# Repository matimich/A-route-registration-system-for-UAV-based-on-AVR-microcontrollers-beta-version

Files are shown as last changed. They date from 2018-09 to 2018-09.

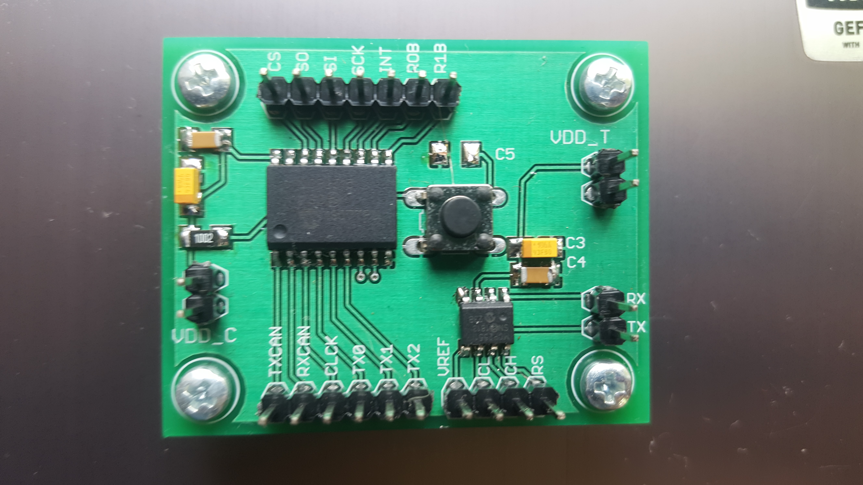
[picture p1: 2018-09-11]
EAGLE/CAN_module.jpg

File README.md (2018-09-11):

Author: Mateusz Michalski

Description:
A route registration system for UAV, based on AVR microcontrollers is a platform consisting of three ATmega microcontrollers, GPS module and an MicroSD card drive. One of the aims of the project was to learn as much communication interfaces as possible, that is why the project includes UART, I2C, SPI, CAN interfaces. All code has been written in C language. To communicate with MicroSD card drive "FatFs" library has been used. In addition, to make communication with CAN, MCP2515 module and MCP2551 transciver have been used. Working with this components reqiured to attached elements from "" library into the project.
Because project was made mostly for a educational purposes, additionaly, two PCB projects were designed and produced. One of them was a shrinked ATmega 32 starter kit and the second was the board to make communication with CAN between uC(board includes MCP2515 module and MCP2551 transciver).

The project was made as diploma thesis.

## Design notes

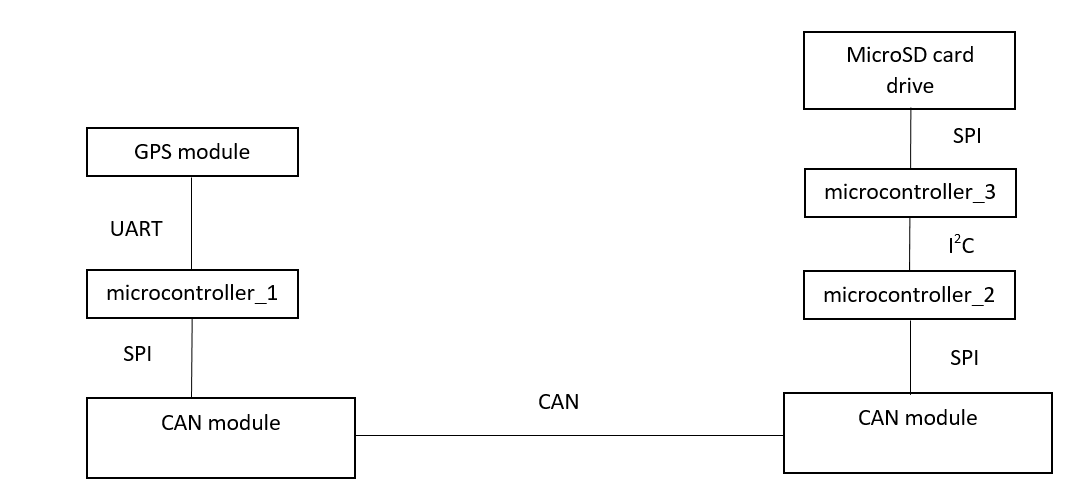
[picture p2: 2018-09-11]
scheme.png

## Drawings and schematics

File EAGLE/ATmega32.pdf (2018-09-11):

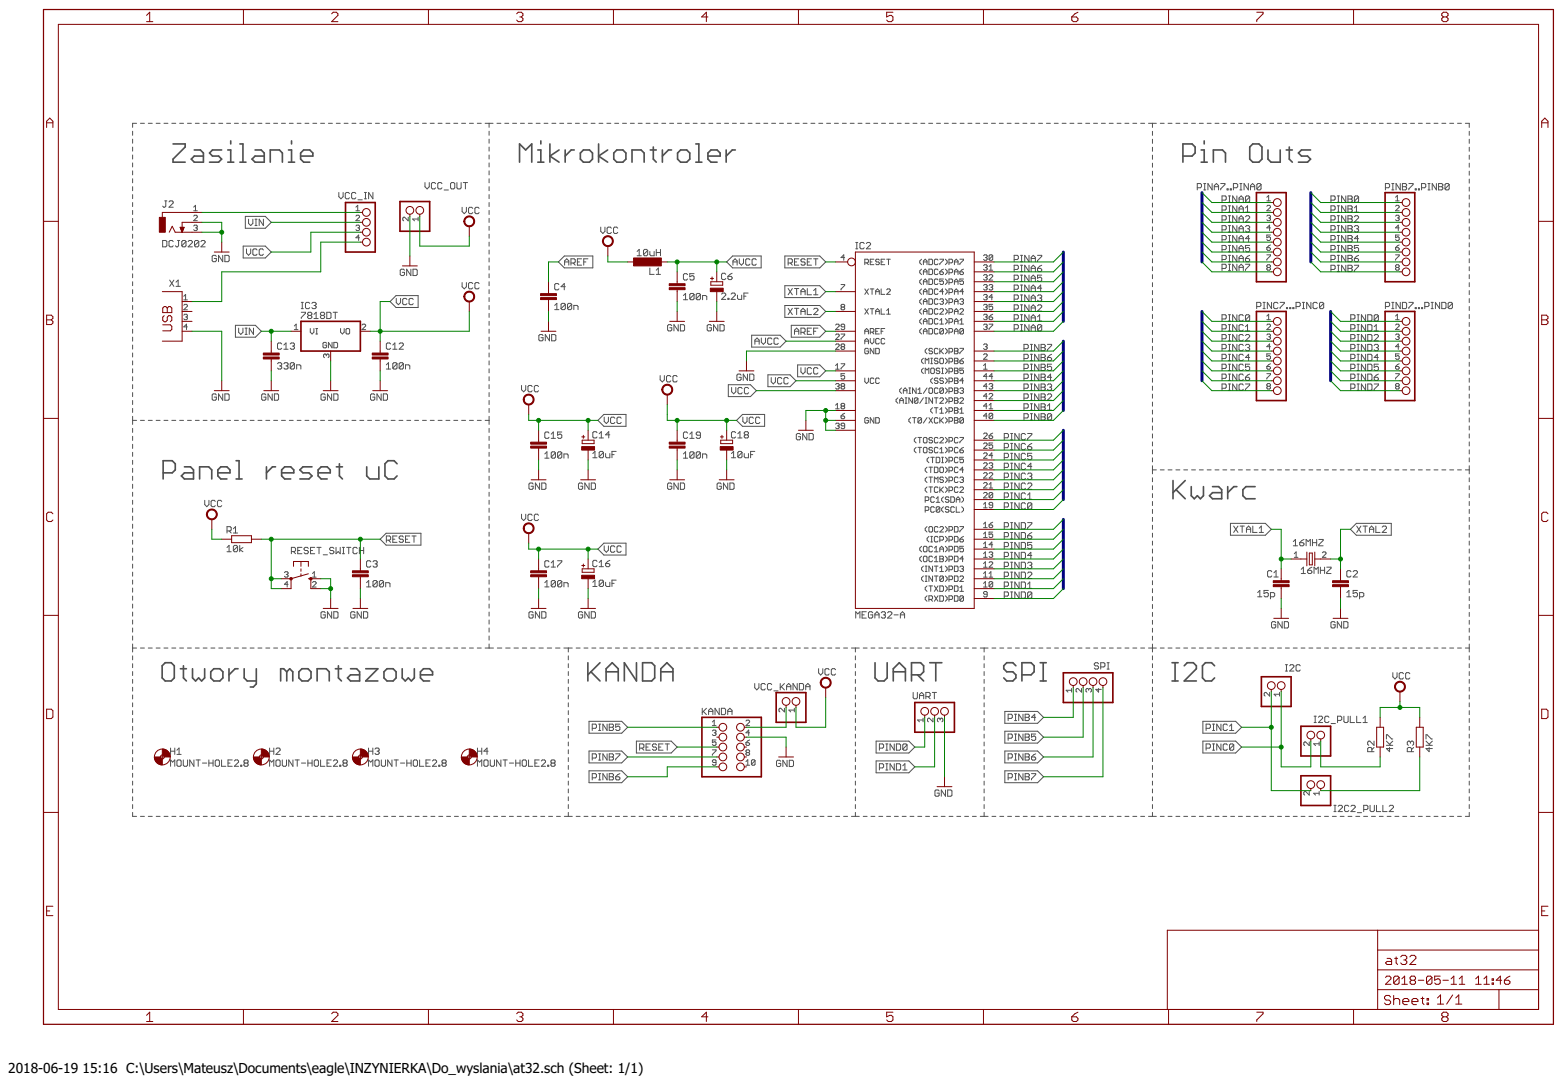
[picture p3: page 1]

2018-06-19 15:16 C:\Users\Mateusz\Documents\eagle\INZYNIERKA\Do_wyslania\at32.sch (Sheet: 1/1)

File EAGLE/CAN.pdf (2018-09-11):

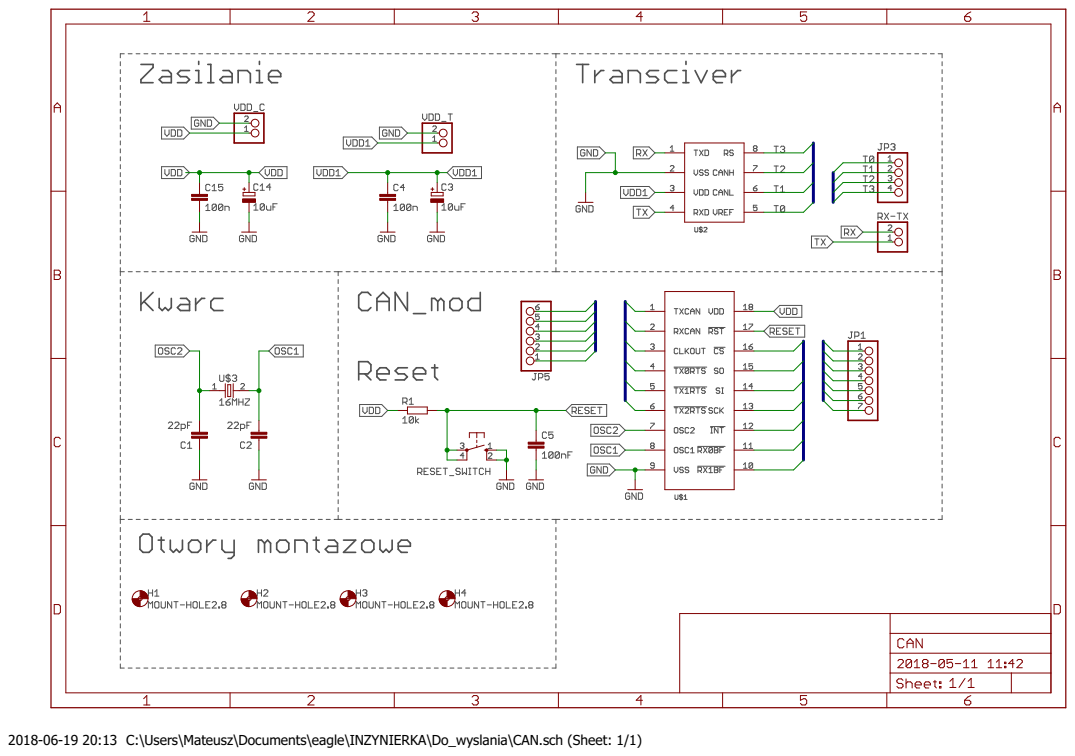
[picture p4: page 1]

2018-06-19 20:13 C:\Users\Mateusz\Documents\eagle\INZYNIERKA\Do_wyslania\CAN.sch (Sheet: 1/1)

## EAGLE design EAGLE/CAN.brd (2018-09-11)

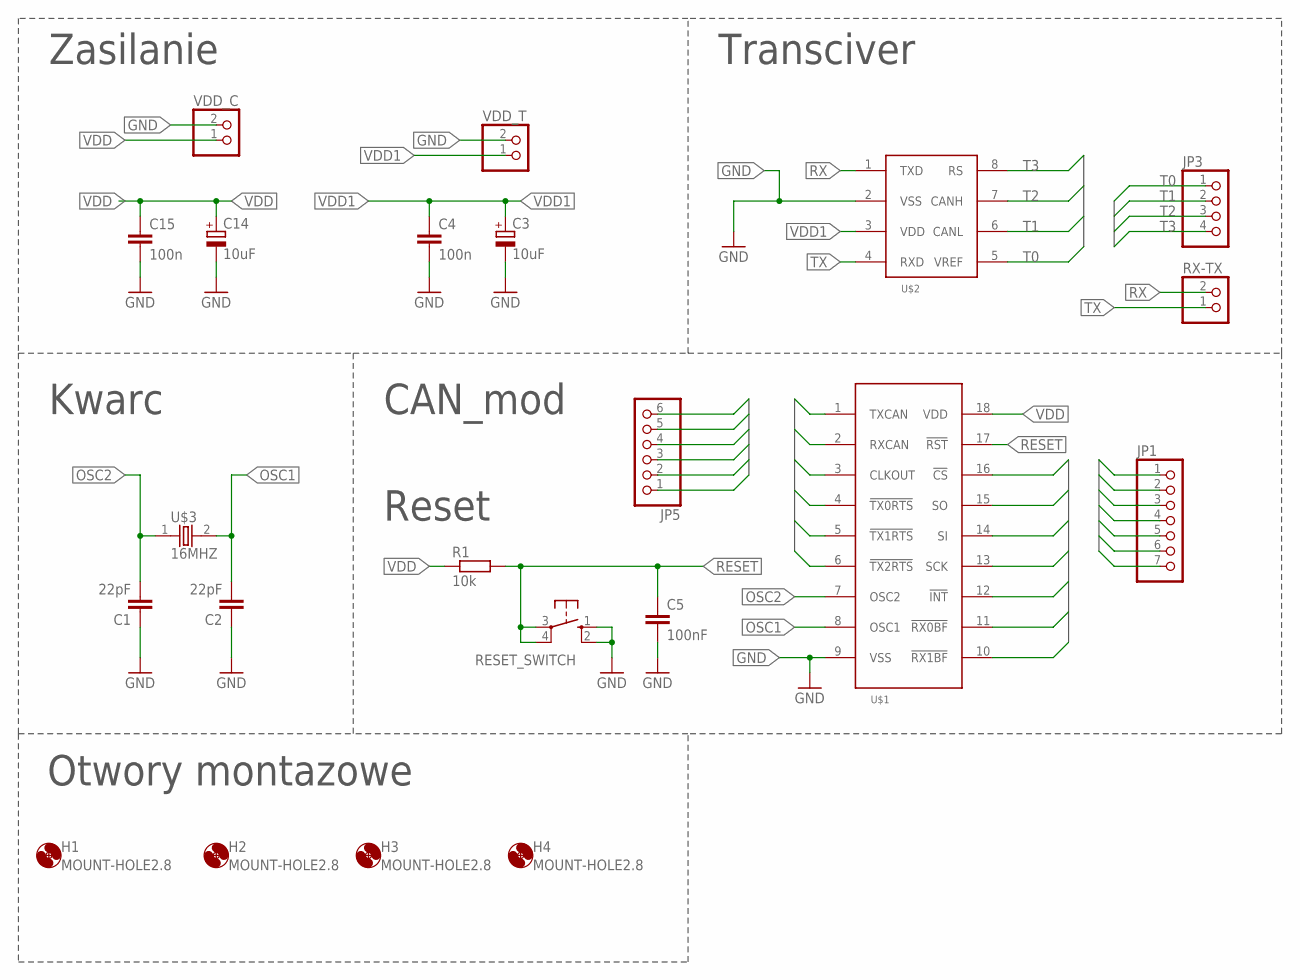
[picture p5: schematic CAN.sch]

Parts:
C1, C2: 22pF; C3216
C3, C14: 10uF; A/3216-18W
C4, C15: 100n; C1206K
C5: 100nF; C1206K
H1, H2, H3, H4: MOUNT-HOLE2.8; 2,8
JP1: PINHD-1X7MAT_LCD; 1X07
JP3: PINHD-1X4; 1X04
JP5: PINHD-1X6MAT6; 1X06
R1: 10k; R3216
RESET_SWITCH: 10-XX; B3F-10XX
RX-TX: PINHD-1X2; 1X02
U$1: MCP2515
U$2: MCP2551
U$3: 16MHZ; HC49SM
VDD_C: PINHD-1X2; 1X02
VDD_T: PINHD-1X2; 1X02

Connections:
CAN0: JP1.1, U$1.10 (!RX1BF)
CAN1: JP1.2, U$1.11 (!RX0BF)
CAN2: JP1.3, U$1.12 (!INT)
CAN3: JP1.4, U$1.13 (SCK)
CAN4: JP1.5, U$1.14 (SI)
CAN5: JP1.6, U$1.15 (SO)
CAN6: JP1.7, U$1.16 (!CS)
CANL0: JP5.1, U$1.6 (!TX2RTS)
CANL1: JP5.2, U$1.5 (!TX1RTS)
CANL2: JP5.3, U$1.4 (!TX0RTS)
CANL3: JP5.4, U$1.3 (CLKOUT)
CANL4: JP5.5, U$1.2 (RXCAN)
CANL5: JP5.6, U$1.1 (TXCAN)
GND: C1.1, C2.1, C3.-, C4.2, C5.2, C14.-, C15.2, RESET_SWITCH.1 (S), RESET_SWITCH.2 (S1), U$1.9 (VSS), U$2.2 (VSS), VDD_C.2 (1), VDD_T.2 (1)
OSC1: C2.2, U$1.8 (OSC1), U$3.2
OSC2: C1.2, U$1.7 (OSC2), U$3.1
RESET: C5.1, R1.2, RESET_SWITCH.3, RESET_SWITCH.4 (P1), U$1.17 (!RST)
RX: RX-TX.2 (1), U$2.1 (TXD)
T0: JP3.1, U$2.5 (VREF)
T1: JP3.2, U$2.6 (CANL)
T2: JP3.3, U$2.7 (CANH)
T3: JP3.4, U$2.8 (RS)
TX: RX-TX.1 (2), U$2.4 (RXD)
VDD: C14.+, C15.1, R1.1, U$1.18 (VDD), VDD_C.1 (2)
VDD1: C3.+, C4.1, U$2.3 (VDD), VDD_T.1 (2)

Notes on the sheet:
Zasilanie
Transciver
Kwarc
CAN_mod
Reset
Otwory montazowe

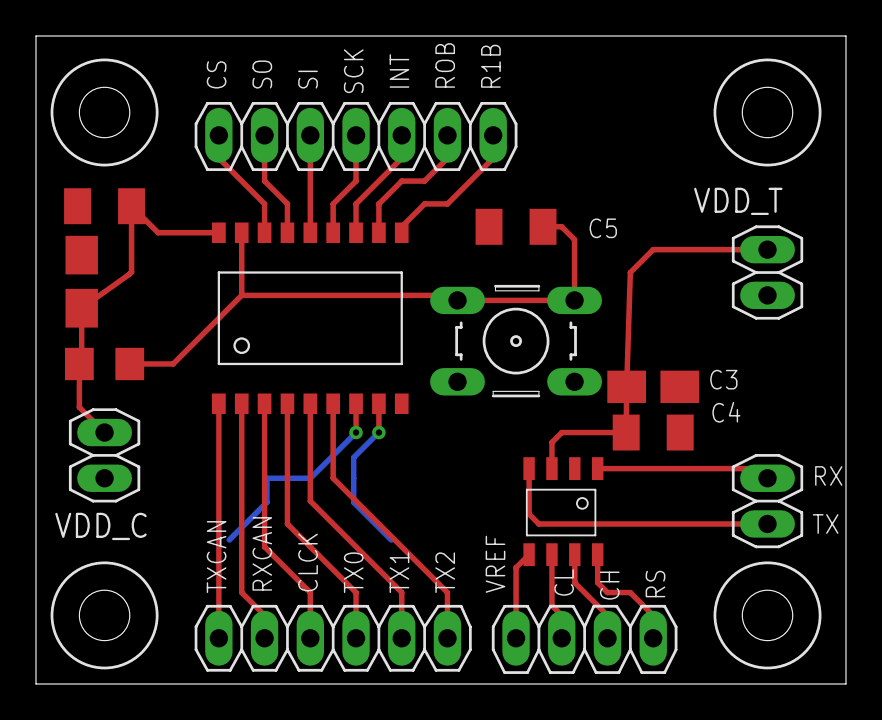
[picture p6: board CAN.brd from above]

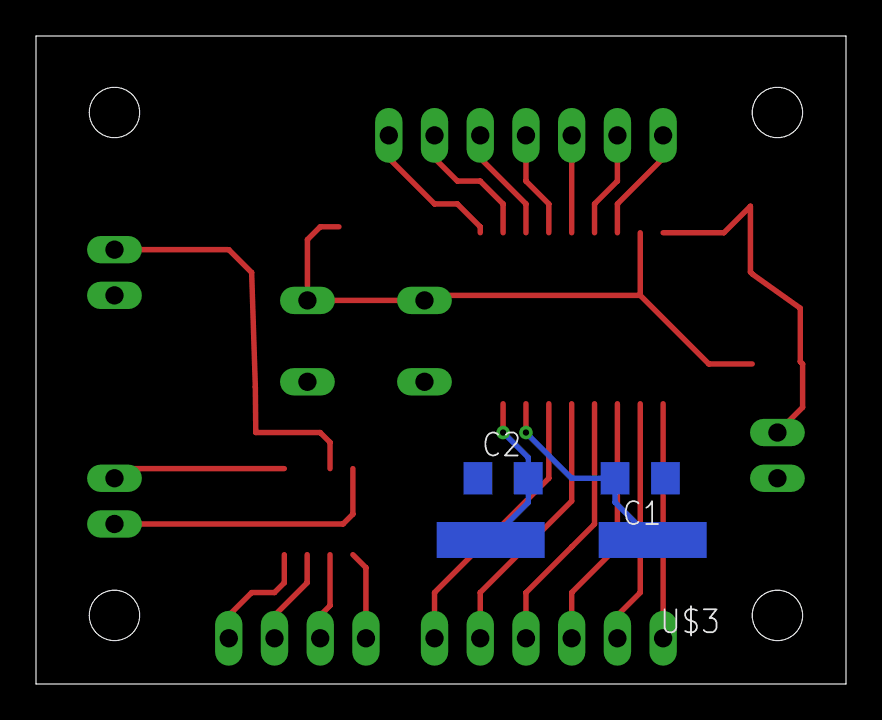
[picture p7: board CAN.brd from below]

Board: 2 copper layers, 45.0 x 36.0 mm, 22 parts (3 on the bottom side), 25 nets.

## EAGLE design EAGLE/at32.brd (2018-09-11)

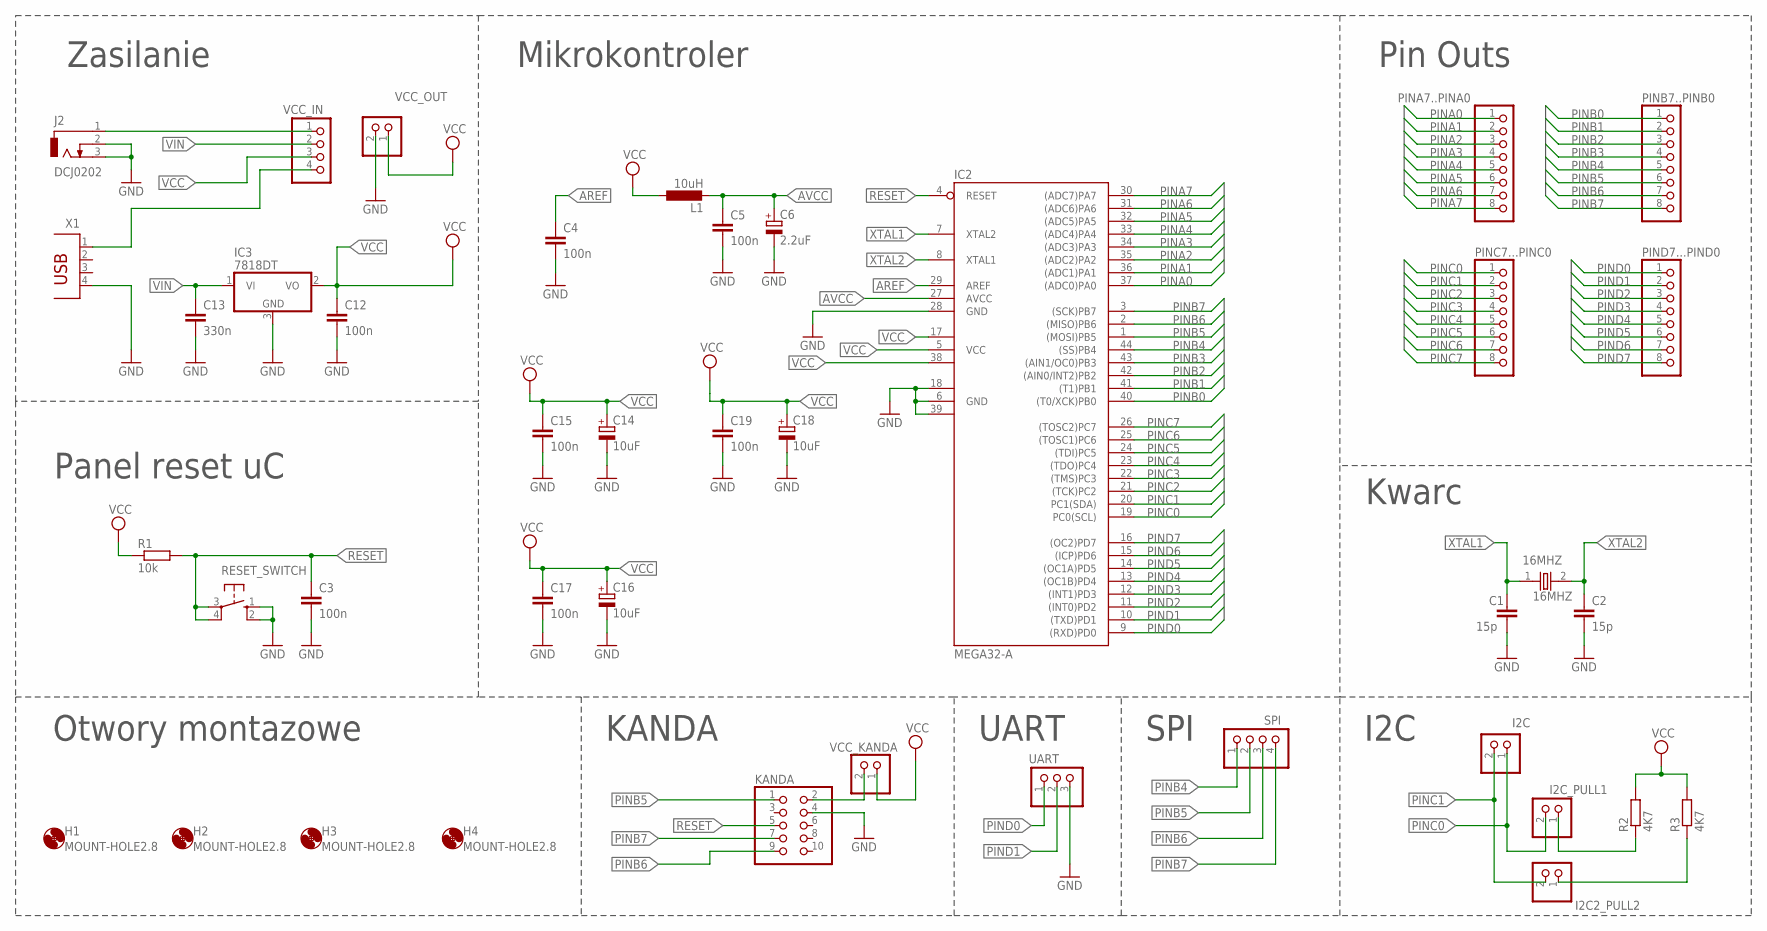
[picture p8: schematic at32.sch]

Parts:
16MHZ: 16MHZ; HC49SM
C1, C2: 15p; C1206K
C3, C4, C5, C12, C15, C17, C19: 100n; C1206K
C6: 2.2uF; A/3216-18W
C13: 330n; C1206K
C14, C16, C18: 10uF; A/3216-18W
H1, H2, H3, H4: MOUNT-HOLE2.8; 2,8
I2C, I2C2_PULL2, I2C_PULL1: PINHD-1X2; 1X02
IC2: MEGA32-A; TQFP44
IC3: 7818DT; TO252
J2: DCJ0202
KANDA: PINHD-2X5; 2X05
L1: 10uH; L3225M
PINA7..PINA0: PINHD-1X8MAT8; 1X08
PINB7..PINB0: PINHD-1X8MAT8; 1X08
PINC7...PINC0: PINHD-1X8MAT8; 1X08
PIND7...PIND0: PINHD-1X8MAT8; 1X08
R1: 10k; R3216
R2, R3: 4K7; R3216
RESET_SWITCH: 10-XX; B3F-10XX
SPI: PINHD-1X4; 1X04
UART: PINHD-1X3; 1X03
VCC_IN: PINHD-1X4; 1X04
VCC_KANDA: PINHD-1X2; 1X02
VCC_OUT: PINHD-1X2; 1X02
X1: PN87520

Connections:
AREF: C4.1, IC2.29 (AREF)
AVCC: C5.1, C6.+, IC2.27 (AVCC), L1.2
GND: C1.2, C2.2, C3.2, C4.2, C5.2, C6.-, C12.2, C13.2, C14.-, C15.2, C16.-, C17.2, C18.-, C19.2, IC2.6 (GND), IC2.18 (GND1), IC2.28 (GND), IC2.39 (GND2), IC3.3 (GND), J2.2, J2.3, KANDA.4, RESET_SWITCH.1 (S), RESET_SWITCH.2 (S1), UART.3, VCC_OUT.2 (1), X1.4
unnamed: I2C2_PULL2.1 (2), R3.1
unnamed: J2.1, VCC_IN.1
unnamed: I2C_PULL1.1 (2), R2.1
unnamed: VCC_IN.4, X1.1
unnamed: KANDA.2, VCC_KANDA.2 (1)
PINA0: IC2.37 ((ADC0)PA0), PINA7..PINA0.1
PINA1: IC2.36 ((ADC1)PA1), PINA7..PINA0.2
PINA2: IC2.35 ((ADC2)PA2), PINA7..PINA0.3
PINA3: IC2.34 ((ADC3)PA3), PINA7..PINA0.4
PINA4: IC2.33 ((ADC4)PA4), PINA7..PINA0.5
PINA5: IC2.32 ((ADC5)PA5), PINA7..PINA0.6
PINA6: IC2.31 ((ADC6)PA6), PINA7..PINA0.7
PINA7: IC2.30 ((ADC7)PA7), PINA7..PINA0.8
PINB0: IC2.40 ((T0/XCK)PB0), PINB7..PINB0.1
PINB1: IC2.41 ((T1)PB1), PINB7..PINB0.2
PINB2: IC2.42 ((AIN0/INT2)PB2), PINB7..PINB0.3
PINB3: IC2.43 ((AIN1/OC0)PB3), PINB7..PINB0.4
PINB4: IC2.44 ((SS)PB4), PINB7..PINB0.5, SPI.1
PINB5: IC2.1 ((MOSI)PB5), KANDA.1, PINB7..PINB0.6, SPI.2
PINB6: IC2.2 ((MISO)PB6), KANDA.9, PINB7..PINB0.7, SPI.3
PINB7: IC2.3 ((SCK)PB7), KANDA.7, PINB7..PINB0.8, SPI.4
PINC0: I2C.1 (2), I2C_PULL1.2 (1), IC2.19 (PC0(SCL)), PINC7...PINC0.1
PINC1: I2C.2 (1), I2C2_PULL2.2 (1), IC2.20 (PC1(SDA)), PINC7...PINC0.2
PINC2: IC2.21 ((TCK)PC2), PINC7...PINC0.3
PINC3: IC2.22 ((TMS)PC3), PINC7...PINC0.4
PINC4: IC2.23 ((TDO)PC4), PINC7...PINC0.5
PINC5: IC2.24 ((TDI)PC5), PINC7...PINC0.6
PINC6: IC2.25 ((TOSC1)PC6), PINC7...PINC0.7
PINC7: IC2.26 ((TOSC2)PC7), PINC7...PINC0.8
PIND0: IC2.9 ((RXD)PD0), PIND7...PIND0.1, UART.1
PIND1: IC2.10 ((TXD)PD1), PIND7...PIND0.2, UART.2
PIND2: IC2.11 ((INT0)PD2), PIND7...PIND0.3
PIND3: IC2.12 ((INT1)PD3), PIND7...PIND0.4
PIND4: IC2.13 ((OC1B)PD4), PIND7...PIND0.5
PIND5: IC2.14 ((OC1A)PD5), PIND7...PIND0.6
PIND6: IC2.15 ((ICP)PD6), PIND7...PIND0.7
PIND7: IC2.16 ((OC2)PD7), PIND7...PIND0.8
RESET: C3.1, IC2.4 (RESET), KANDA.5, R1.2, RESET_SWITCH.3, RESET_SWITCH.4 (P1)
VCC: C12.1, C14.+, C15.1, C16.+, C17.1, C18.+, C19.1, IC2.5 (VCC), IC2.17 (VCC1), IC2.38 (VCC2), IC3.2 (VO), L1.1, R1.1, R2.2, R3.2, VCC_IN.3, VCC_KANDA.1 (2), VCC_OUT.1 (2)
VIN: C13.1, IC3.1 (VI), VCC_IN.2
XTAL1: 16MHZ.1, C1.1, IC2.7 (XTAL2)
XTAL2: 16MHZ.2, C2.1, IC2.8 (XTAL1)

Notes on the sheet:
Panel reset uC
Otwory montazowe
Zasilanie
Mikrokontroler
Pin Outs
Kwarc
KANDA
UART
SPI
I2C

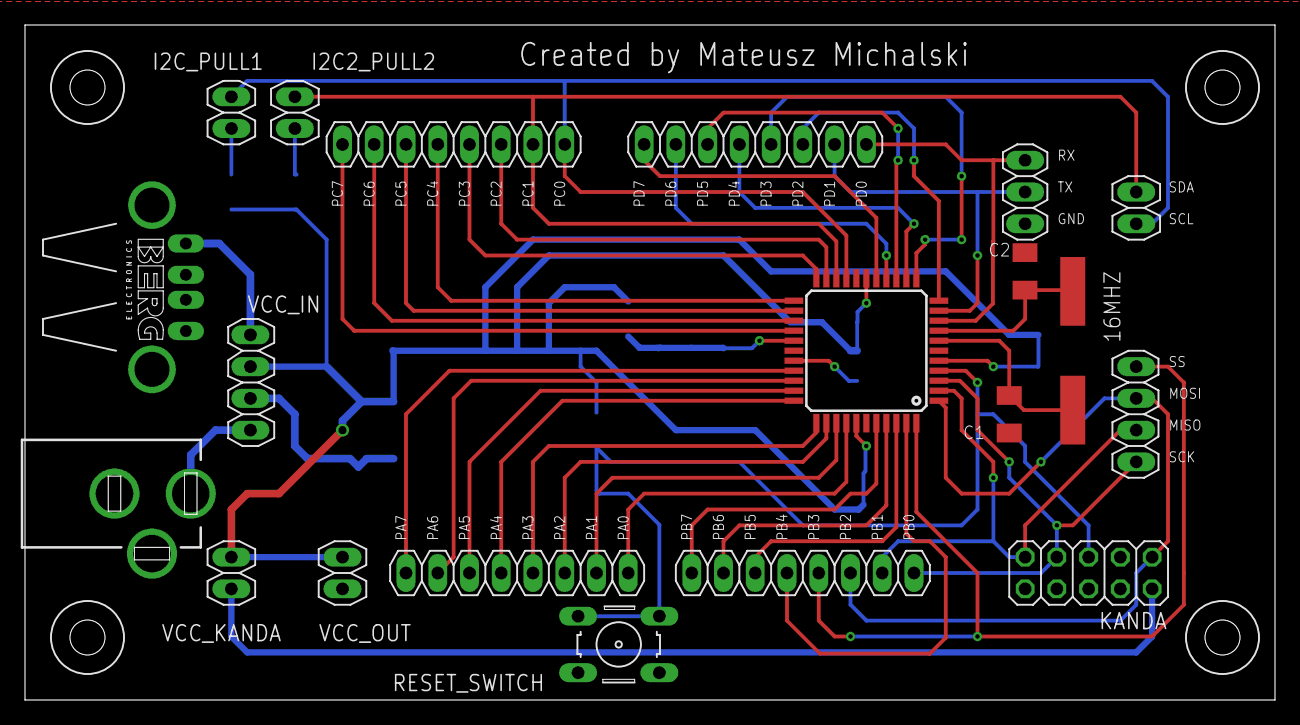
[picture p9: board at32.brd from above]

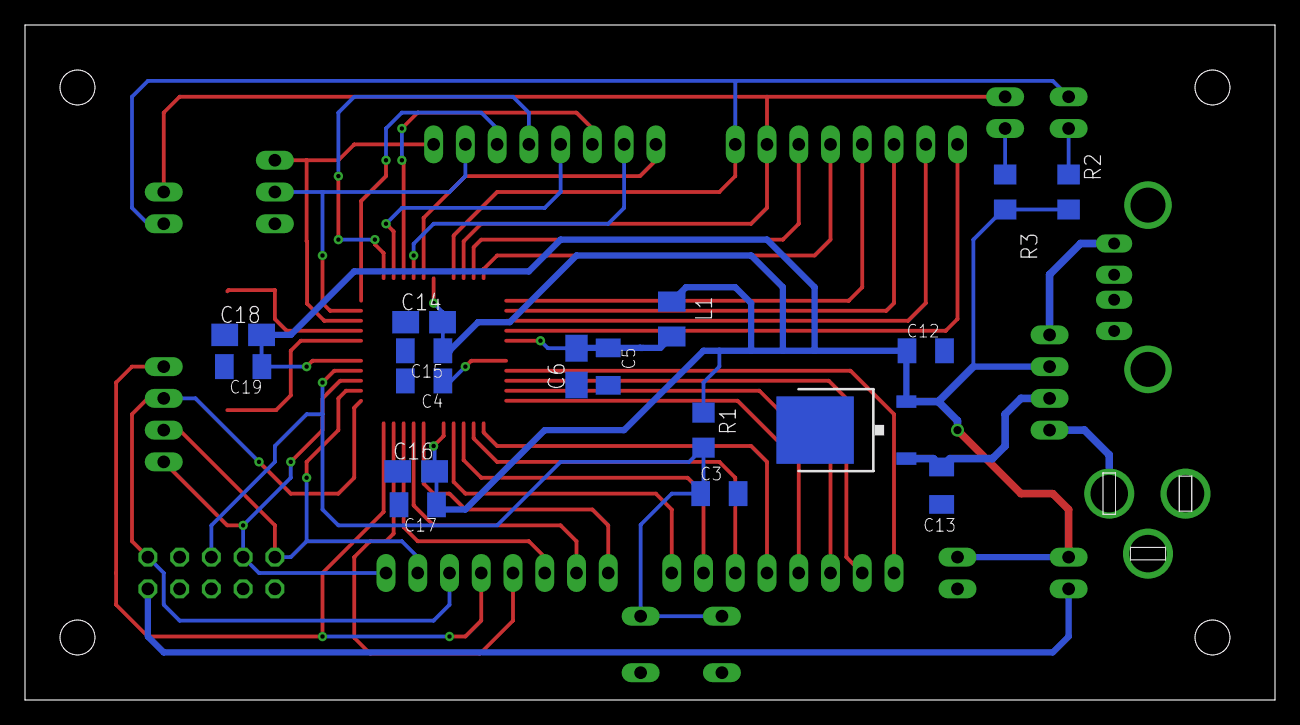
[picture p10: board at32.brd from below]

Board: 2 copper layers, 100.0 x 54.0 mm, 41 parts (17 on the bottom side), 45 nets.

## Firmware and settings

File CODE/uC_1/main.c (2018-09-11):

/*
 *  main.c
 *
 *  Author	: Mateusz Michalski
 *  uC	 	: Atmel AVR ATmega 32
 *  Compiler 	: avr-gcc
 */


#include <avr/io.h>
#include "uart.h"
#include "can.h"
#include "spi.h"
#include <avr/interrupt.h>
#include <util/delay.h>


volatile uint8_t uart_interrupt_delay;

int main(void)
{
	Dane.id = 0x12;
	Dane.rtr = 0;
	Dane.length =1;
	Dane.data ='z';


	USART_Init(__UBRR);	// UART INITIALIZATION
	mcp2515_init();	//  CAN MODULE INITIALIZATION
	sei();	// INTERRUPT



	while(1)
	{

		if(uart_interrupt_delay ==1)	// DATA FROM GPS RECEIVED
		{
			Dane.data = UART_data_rx();
			can_send_message(&Dane);	//SENDING DATA 
			uart_interrupt_delay=0;		// FLAG = 0
		}

	}

	return 0;
}

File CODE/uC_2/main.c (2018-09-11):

/*
 *  main.c
 *
 *  Author	: Mateusz Michalski
 *  uC	 	: Atmel AVR ATmega 32
 *  Compiler 	: avr-gcc
 */

#include <avr/io.h>
#include "can.h"
#include "twi.h"
#include <avr/interrupt.h>
#include <util/delay.h>
#include "spi.h"


//macros for pins setting 
#define PORT(x) SPORT(x)
#define SPORT(x) (PORT##x)

#define PIN(x) SPIN(x)
#define SPIN(x) (PIN##x)

#define DDR(x) SDDR(x)
#define SDDR(x) (DDR##x)

#define PORT_INT A
#define PIN_INT PA1





int main(void)
{
	//setting CAN pin interrupt
	DDR(PORT_INT) &= ~(1<<PIN_INT); //setting pin as input 
	PORT(PORT_INT) |= (1<<PIN_INT); // pull up pin to VCC

	Dane.id = 0x12;
	Dane.rtr = 0;
	Dane.length =1;
	Dane.data ='O';

	InitSPI();	// SPI initialization
	mcp2515_init();	// CAN module initialization
	i2cSetBitrate(3,1);

	sei();	// setting Interrupt 


	while(1)
	{
		if(!(PIN(PORT_INT) & (1<< PIN_INT))) //Interrupt set flag when data appears 
		{
			can_get_message(&Dane);	//receiving data from CAN
			i2c_write_all_proc(ATMEGA_32_uC_3_SLAVE_ADRES,&Dane.data); //sending data using I2C
		}

	}
	return 0;
}






	

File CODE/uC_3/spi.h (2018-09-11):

/*
 *  spi.h
 *
 *  Author	: Mateusz Michalski
 *  uC	 	: Atmel AVR ATmega 32
 *  Compiler 	: avr-gcc
 */

#ifndef SPI_H_
#define SPI_H_

//FOR ATMEGA 32
#define MOSI PB5
#define MISO PB6
#define SCK	PB7
#define CS PB4
#define CS_2 PB3

void InitSPI(void);	// SPI INITIALIZATION
void SPI_sent(uint8_t data);	//SENDING SIGN
uint8_t SPI_receive(void);	//RECEIVING SIGN
uint8_t SPI_T_R(uint8_t data);	// SEND/RECEIVE SIGN SIMULTANEOUSLY

#endif /* SPI_H_ */
